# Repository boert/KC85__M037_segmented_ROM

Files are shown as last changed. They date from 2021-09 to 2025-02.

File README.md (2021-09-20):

# KC85__M037_segmented_ROM
Modul für den KC85/3/4/5: Segmentierter ROM in den Größen 32/64/128 kByte

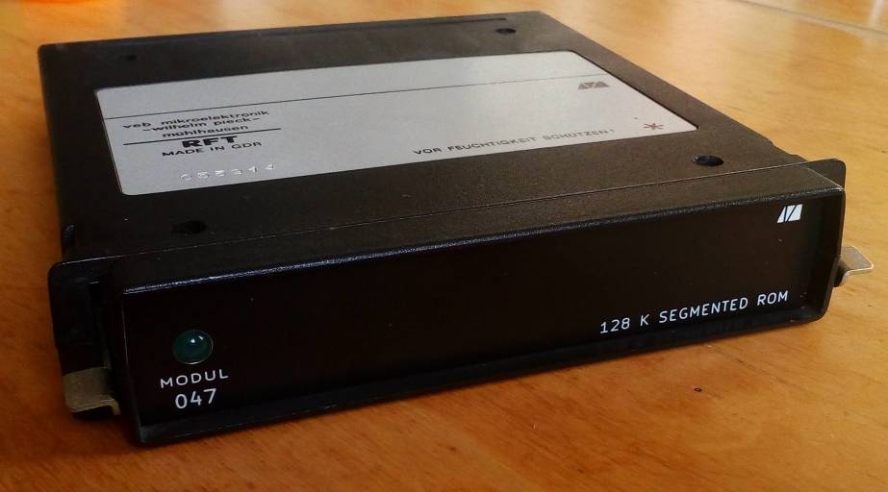
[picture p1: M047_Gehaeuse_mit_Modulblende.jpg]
Modul


optionale Bedienoberfläche

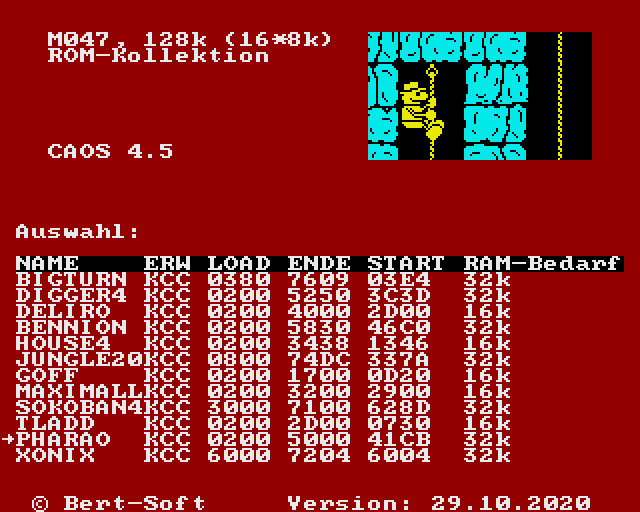
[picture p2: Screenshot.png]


## Verzeichnisübersicht

Verzeichnis             | Inhalt
-----------             | ------
Platine                 | Schaltplan, Layout und Stückliste/BOM
EPROM-Images            | vorgefertigt, für Emulator und EPROM-Brenner
Generator-Software      | um eigene EPROM-Images zu erstellen (C++, Qt5)
ROMSTART                | Menüsoftware, die auf dem Modul läuft (Z80-Assembler)

## Credits

Dieses Projekt nutzt u.a. folgende Software:
- KiCad, https://www.kicad.org/
- pasmo, https://pasmo.speccy.org/
- Python, https://www.python.org/
- Qt, https://www.qt.io/
- ZX7, https://spectrumcomputing.co.uk/entry/27996/ZX-Spectrum/ZX7

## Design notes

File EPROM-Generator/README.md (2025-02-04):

Die Software dient zum Erzeugen von EPROM-Inhalten für KC85-Module vom
Typ M045/M046/M047. Die EPROM-Software ist auf den Modellen KC85/3 und KC85/4 aus Mühlhausener Produktion, sowie den Umbauten zum KC85/5 lauffähig.

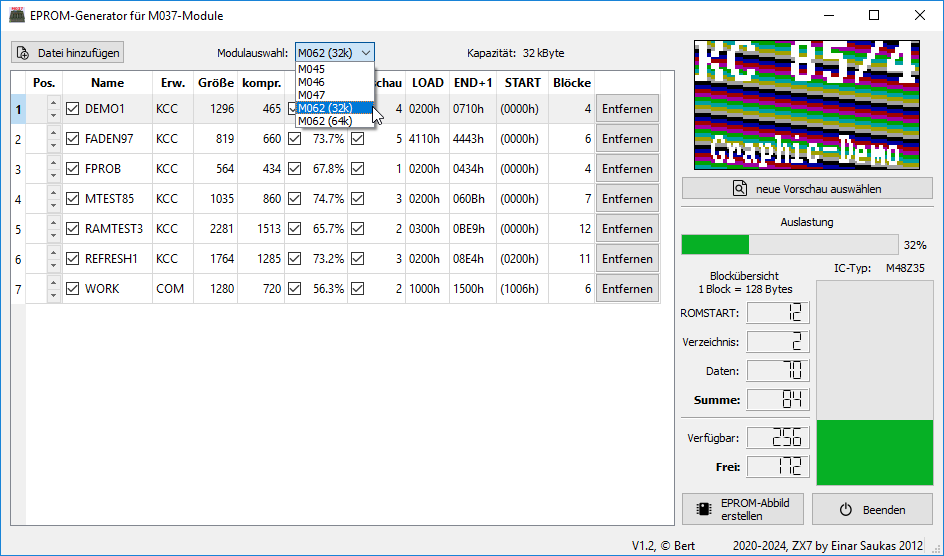
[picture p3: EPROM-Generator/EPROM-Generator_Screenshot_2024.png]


# Bedienung

Im Wesentlich besteht der Programmablauf aus vier Schritten:
1. Auswahl des Modultyps
2. Hinzufügen von KCC-Dateien
3. (optional) Auswahl der Vorschaubilder
4. Erzeugen des EPROM-Abbildes

## Start der Software

Beim Start von der Kommandozeile, können optional eine oder mehrere KCC-Dateien als Parameter mitgegeben werden.
Anschließend öffnet sich das zweigeteilte Hauptfenster. Im linken Teil befindet sich eine Liste der KC-Programme, die zum EPROM hinzugefügt werden sollen. Im rechten Teil befinden sich ein Vorschaubild, Statusinformationen und die Schaltflächen um den EPROM-Inhalt zu generieren bzw. das Programm zu beenden.
Links oben befindet sich die Schaltfläche zum Hinzufügen von Dateien, sowie die Möglichkeit den Modultyp zu ändern.

## Modultyp

Die Wahl des Modultypes wirkt sich auf den verfügbaren Speicherplatz aus.
Der ausgewählte Modultyp muß zu den verwendeten EPROMs und den Jumpereinstellungen auf der Platine passen. Die ROMSTART-Software, welche im KC ausgeführt wird, ist auf den jeweiligen Modultyp zugeschnitten.

## Programme

Momentan werden nur KCC-Dateien unterstützt. KCC-Dateien bestehen aus Blöcken zu je 128 Byte. Im ersten Block, dem Vorblock, sind Zusatzinformationen, wie der Name und die verwendeten Adressen hinterlegt (siehe auch [1]).
Diese Informationen werden in der Tabelle auf der linken Seite dargestellt, können dort aber nicht geändert werden.
Die Programmgröße wird in Bytes angegeben. Da in ROMSTART der Entpacker DZX7 [2] integriert ist, werden die Programme, bei denen es sich lohnt komprimiert im EPROM abgelegt.
Die komprimierte Größe und das Kompressionsverhältnis werden ebenfalls in der Tablle dargestellt. Die Spalte "Blöcke" enthält die Zahl der tatsächlich im EPROM benötigten 128 Byte-Blöcke.

Folgende Einstellungen können in der Tabelle vorgenommen werden:
- Ändern der Reihenfolge (dazu die Pfeile in Spalte "Pos." verwenden)
- Auswahl ob das Programm mit in den EPROM übernommen wird (Häckchen in Spalte "Name")
- Auswahl ob das Programm komprimiert wird (Häckchen in Spalte "Ratio")
- Auswahl eine Vorschau mit übernommen wird (Häckchen in Spalte "Vorschau")
- Dauerhaftes Entfernen eines Listeneintrags (letzte Spalte)

## Vorschau

Zu jedem Programmeintrag kann eine Vorschau ausgewählt bzw. angezeigt werden.
Um eine neue Vorschau zu erzeugen, wird die entsprechende Schaltfläche ausgewählt.
Es öffnet sich ein Dialog in dem ggf. die bisherige Vorschau dargestellt wird.
Im Dialog bestehen folgende Möglichkeiten:
- Öffnen einer PNG bzw. JPEG-Datei
- Öffnen einer PIC-Datei (Bildschirmauszug vom KC85/3)
- Öffnen einer PIP/PIF-Datei (Bildschirmauszug vom KC85/4)

Anschließend wird in der linken oberen Ecke ein Auswahlrechteck dargestellt, welches mit der Maus verschoben werden kann. Wenn der richtige Ausschnitt gefunden wurde, kann die Auswahl mit "Speichern" als ICN-Datei (Icon) gesichert werden.

Eine gute Möglichkeit um an passende Vorschaubilder zu erzeugen, bietet der Emulator JKCEMU [3].
Der Emulator läßt sich pausieren (Alt-P) und man kann den Bildschriminhalt als Datei sichern (Datei -> Bildschirmausgabe -> als Bilddatei speichern).
Eine nähere Erklärung für PIC/PIP/PIF-Dateien findet sich unter [4]. Im Wesentlichen sind es Bildschirmabzüge der jeweiligen KC-Systeme.
Auf dem System selbst können die Hilfsprogramme PICGEN.KCC oder PICGEN.COM verwendet werden.
Anmerkung: Um PIC/PIP/PIF-Dateien als Vorschau verwenden zu können, müssen diese unkomprimiert vorliegen.

## Statusanzeige

Unterhalb der Vorschau befindet sich eine Statusanzeige.
Dort kann man sehen, wieviel vom Gesamtspeicher schon verwendet wird (waagerechter Balken).
Die vier senkrechten Balken stehen für die einzelnen EPROM-Schaltkreise.
Falls mehr Programme ausgewählt sind, als Platz vorhanden ist, wird der Balken rot eingefärbt.
Es ist dann nicht möglich ein EPROM-Auszug zu erstellen.

Der Speicher im EPROM besteht aus drei Teilen:
1. der Verwaltungs- und Startprogramm (ROMSTART)
2. den Verzeichniseinträgen (28 Byte/Eintrag)
3. den Programmdaten
Der benötigte Platz für alle drei Teile wird unter "Summe" angezeigt.
Darunter ist die Zahl der verfügbaren Blöcke zu sehen (Modulabhängig).
Und anschließen ist unter "Frei" die Zahl der freien Blöcke abgebildet.

## Abbild erstellen

Wenn alle benötigten Programme hinzugefügt und die gewünschten Vorschaubilder erstellt sind, wird mit der Schaltfläche "EPROM-Abbild erstellen" die Datei "EPROM_M04?.bin" erstellt. Diese Datei kann sofort im Emulator getestet werden.
Zusätzlich werden die Dateien "EPROM_M04?.bin_ROM?" erstellt. Diese sind für den EPROM-Brenner gedacht.

# Quellenverweise

[1] KC85/5 System-Handbuch CAOS 4.6 bis 4.8, 3.8.2 Dateiaufbau

[2] ZX7, Einar Saukas, https://worldofspectrum.org/infoseekid.cgi?id=0027996

[3] JKCEMU, Jens Müller, http://www.jens-mueller.org/jkcemu/

[4] KC-Bildformate intern, Ralf Kästner, KC-News 2/95, http://kc85.info/index.php/kc-news/265-kc-news-2-1995.html?start=13

# Nachtrag 02/2020

Bei der Nutzung mit einem Modul M052 (USB) kommt es zu Problemen wenn am M052 die Tastatur genutzt werden soll und das ROM-Modul im Schacht 08 steckt.
In diesem Fall verdeckt ein aktiviertes ROM-Modul die Interruptroutinen im ROM des M052.
Workaround: Das ROM-Modul muß auf einem höheren Steckplatz als das M052 Modul betrieben werden. Um dennoch in den Genuß von Autostart zu kommen, läßt sich auf dem verwendeten USB-Stick eine Datei INITIAL.UUU anlegen, welche z.B. folgende Kommandos enthält:
SWITCH C C1
ROMSTART

# Nachtrag 02/2025

Falls es zu Artefakten bei der Erstellung von Vorschaubildern kommen sollte, gibt es hier weitere Hinweise.

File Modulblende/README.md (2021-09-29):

# KiCad-Projekt für die Modulblende

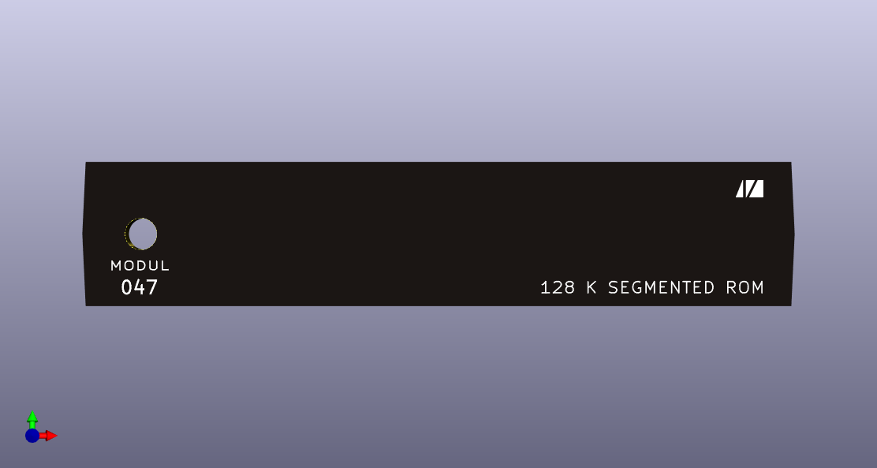
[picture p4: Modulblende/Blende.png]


Vielen Dank an Mirco (ch1frd)!

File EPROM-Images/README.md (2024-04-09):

# EPROM-Inhalte

## M033__TYPESTAR

* Typestar 90 und RAMDOS V2.0

Hier gibt es weitere Informationen zu Typestar: http://www.mpm-kc85.de/html/m033_typestar.htm

## M047__12_Spiele_KC855

diese Spiele laufen alle auf dem KC85/4 mit CAOS 4.2 bis CAOS 4.8

ROMSTART vom 5.12.2020

* Bennion.kcc
* Bigturn
* DELIRO
* DIGGER4
* ENTERPRISE
* GOFF
* HOUSE4
* JUNGLE21
* KCLADDER
* MAXIMALL
* SOKOBAN4
* XONIX

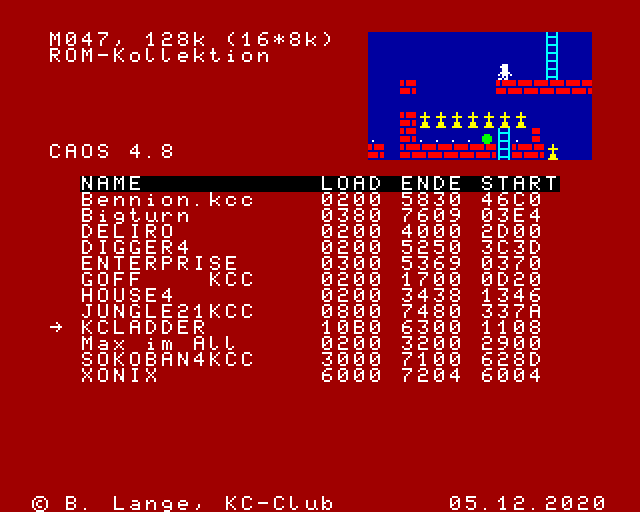
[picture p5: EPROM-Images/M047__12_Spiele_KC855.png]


## M047__14_Spiele_KC853

diese Spiele sind für den KC85/3 gedacht

ROMSTART vom 5.12.2020

* Bennion.kcc
* Bigturn
* BOULDERDASH
* Breakin
* DELIRO
* DIGGER3
* GOFF2
* GOLDRUSH
* HELI
* KEX3
* PHARAO+
* PURSUIT3
* PYRAMIDE
* XONIX

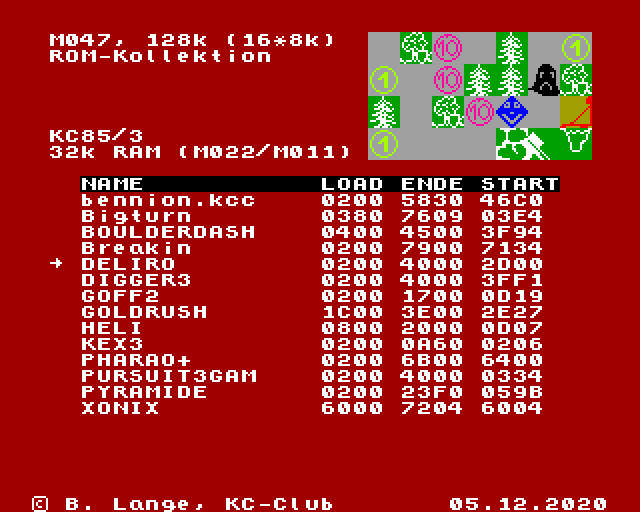
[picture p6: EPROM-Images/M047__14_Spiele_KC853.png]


## M062__7_Tools_KC854

Ein paar kleine Demos und Tools für den KC85/4 bzw. /5

ROMSTART vom 9.4.2024

* DEMO
* FADEN97
* FPROB (Farben probieren)
* MTEST85 (Speichertest)
* RAMTEST3 (Speichertest)
* REFRESH1 (Refreshtest für M036)
* WORK (Hex-Editor)

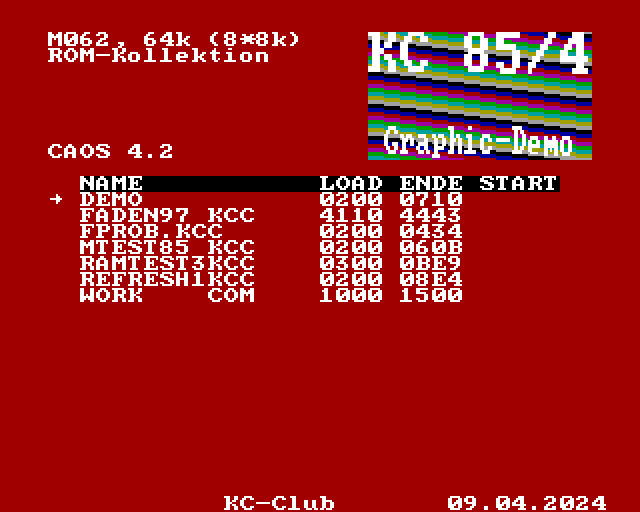
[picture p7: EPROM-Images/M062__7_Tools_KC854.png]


## Copyright

Das Copyright der Software liegt beim jeweiligen Autor!

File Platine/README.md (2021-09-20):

# Unterlagen zur Leiterplatte

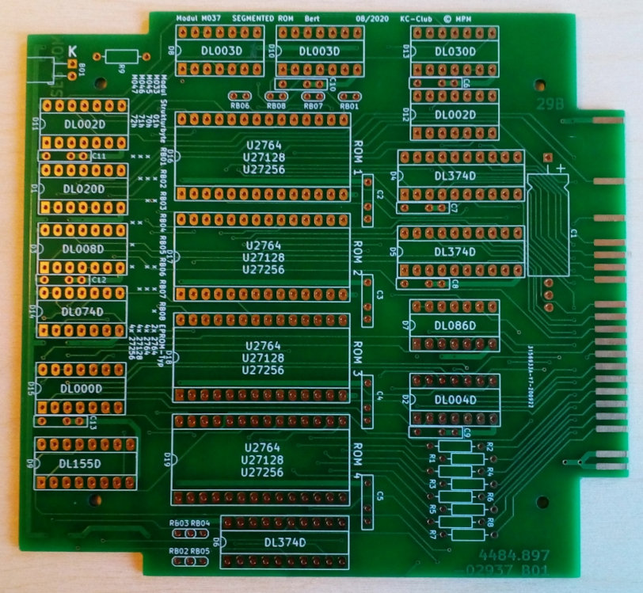
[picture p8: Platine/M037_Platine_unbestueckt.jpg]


Dokument            | Verweis
--------            | -------
Schaltplan          | [M037_Schaltplan.pdf](https://raw.githubusercontent.com/boert/KC85__M037_segmented_ROM/main/Platine/M037_Schaltplan.pdf)
Layout              | [M037_Platine.pdf](https://raw.githubusercontent.com/boert/KC85__M037_segmented_ROM/main/Platine/M037_Platine.pdf)
Stückliste/BOM      | [M037_Stueckliste.xls](https://raw.githubusercontent.com/boert/KC85__M037_segmented_ROM/main/Platine/M037_Stueckliste.xls)
Bestückungshilfe    | [M037_Bestueckhilfe.html](https://raw.githubusercontent.com/boert/KC85__M037_segmented_ROM/main/Platine/M037_Bestueckhilfe.html)

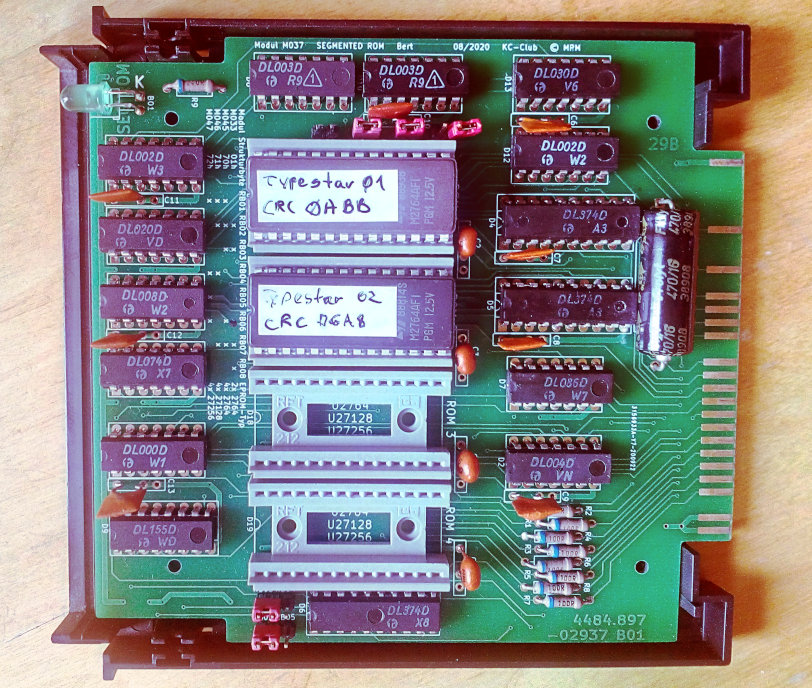
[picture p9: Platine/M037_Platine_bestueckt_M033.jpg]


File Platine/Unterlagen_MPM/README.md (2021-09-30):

# Unterlagen vom VEB Mikroelektronik „Wilhelm Pieck“ Mühlhausen

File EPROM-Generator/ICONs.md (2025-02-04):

# Probleme beim Erstellen von Vorschaubildern (Icons)

Es gibt Fälle, bei denen die EPROM-Generator-Software beim Erzeugen der Vorschaubilder unerwünschte Artefakte erzeugt:
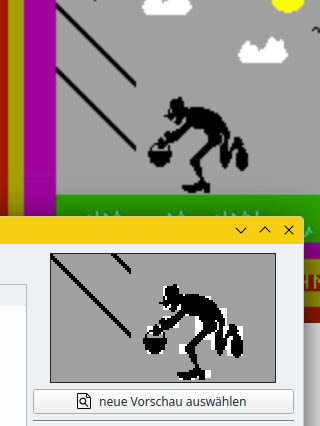
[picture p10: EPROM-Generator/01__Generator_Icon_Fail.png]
fehlerhaftes Icon


Dies tritt bei der Verwendung von Screenshots im PNG-Format auf.
Dort muß die Funktion pixmap_to_bws [1] für  jeweils acht nebeneinanderliegende RGB24-Bildpunkte das passende KC85-Farbbyte finden.
Das klappt offensichtlich nicht immer.

Um trotzdem zu schönen Vorschaubilder zu kommen, gibt es einige Workarounds:

## PICGEN.COM

Damit kann der Inhalt des jeweils nicht angezeigten Bildes als PIP-/PIF-Datei abspeichern werden. Das Programm [2] läuft unter MicroDOS bzw. CP/M und benötigt ein D004 bzw. D008.

## PICGEN.KCC

Das Tool gibt es auch in einer Variante [3] die direkt auf dem Grundgerät D001 läuft.

## JKCEMU
Im JKCEMU [4], dem umfrangreichsten KC-Emulator läst sich die Speicherfunktion nutzen, um PIP- bzw. PIF-Dateien zu erstellen.

Als Dateiformat wird KCC gewählt, der Speicherbereich geht von 7FFFh bis A7FFh und als Dateiendung wählt man PIP.
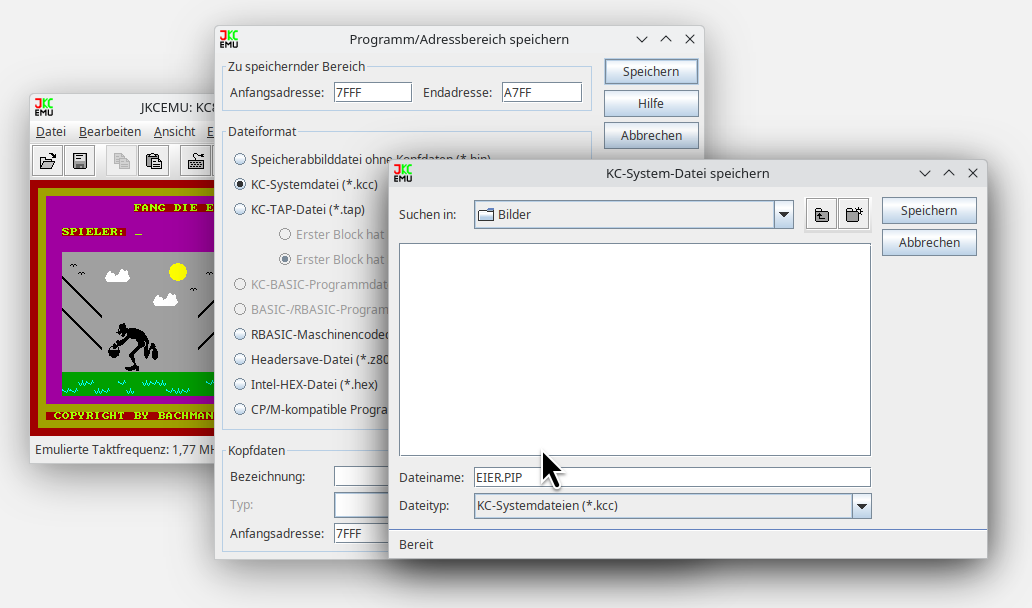
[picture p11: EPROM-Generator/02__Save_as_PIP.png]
Speichern als PIP

Der Bildspeicher startet zwar bei 8000h, aber das PIP-Format hat noch ein Kennbyte, welches direkt vor den Daten kommt. Richtigerweise müßte man das für eine unkomprimierte PIP-Datei auf 5 setzen.

Dann schaltet man mit ESC-9 auf die Farbebene um. Anschließend wird wieder gespeichert:
Das Dateiformat ist wieder KCC, der Speicherbereich geht wieder von 7FFFh bis A7FFh und als Dateiendung wählt man nun PIF.
Die Umschaltung auf die Farbebene klappt aber nur, wenn gerade ein Eingabefeld aktiv ist (CAOS-UP KBD oder KBDS).
Für unkomprimierte PIF-Dateien wäre das richtige Kennbyte die 4.

Anschließend lassen sich die PIP- und die PIF-Datei in der EPROM-Generator-Software auswählen:
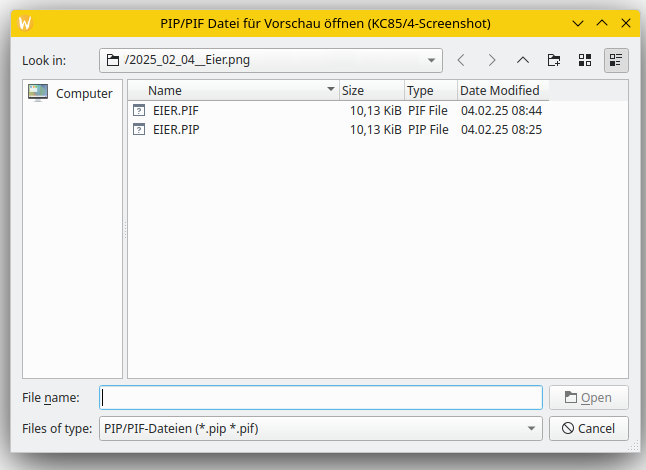
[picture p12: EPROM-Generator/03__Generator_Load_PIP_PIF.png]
Load PIP and PIF

Ggf. falsche Kennbytes werden ignoriert, aber die PIP- bzw. PIF-Dateien müssen unkomprimiert vorliegen.

# Links

[1] https://github.com/boert/KC85__M037_segmented_ROM/blob/main/EPROM-Generator/kc85color.cpp#L72

[2] http://www.kc85.info/index.php/download.html?view=download&id=192:picgen20&catid=6

[3] http://www.kc85.info/index.php/download.html?view=download&id=262:picgen&catid=27

[4] JKCEMU, Jens Müller, http://www.jens-mueller.org/jkcemu/

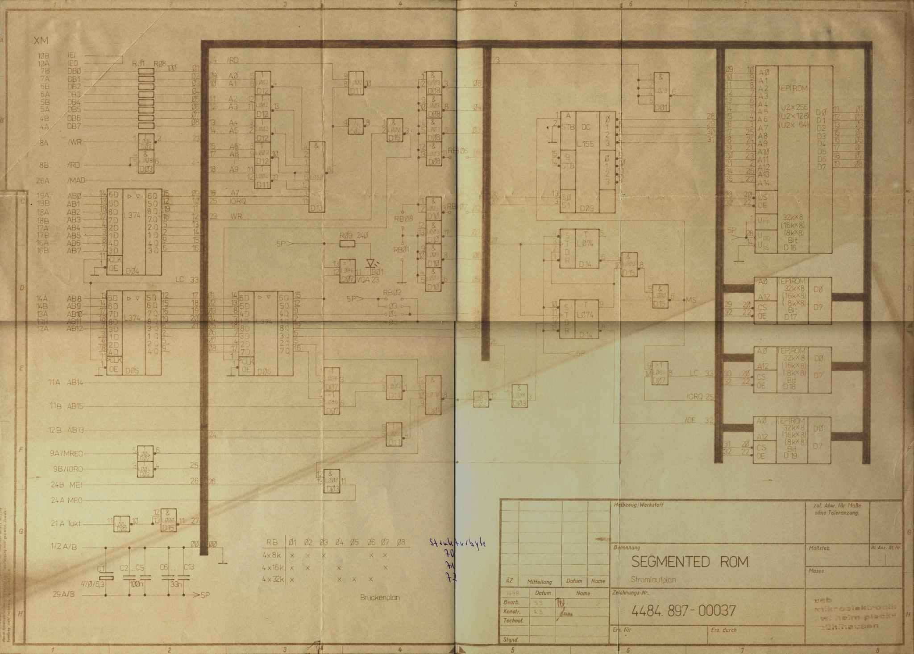
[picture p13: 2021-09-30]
Platine/Unterlagen_MPM/M037_Schaltplan.jpg

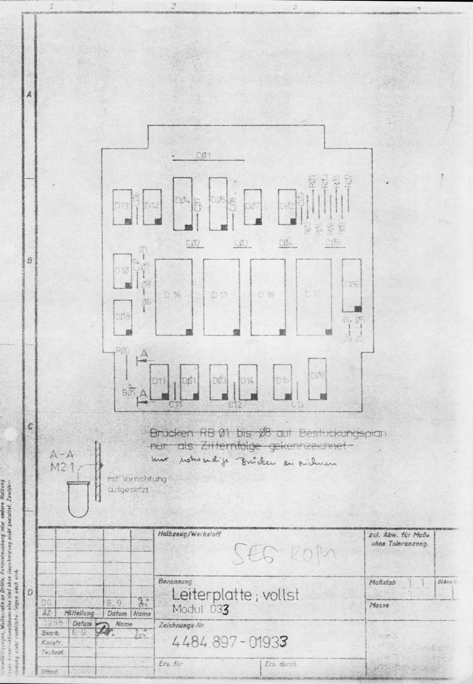
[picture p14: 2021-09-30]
Platine/Unterlagen_MPM/M037_Leiterplatte.jpg

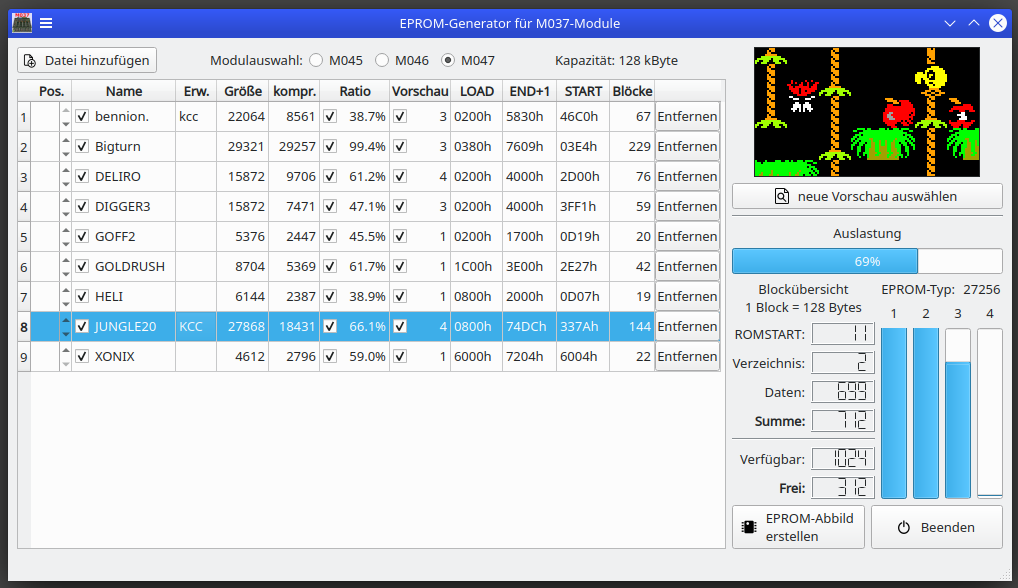
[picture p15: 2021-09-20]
EPROM-Generator/EPROM-Generator_Screenshot.png

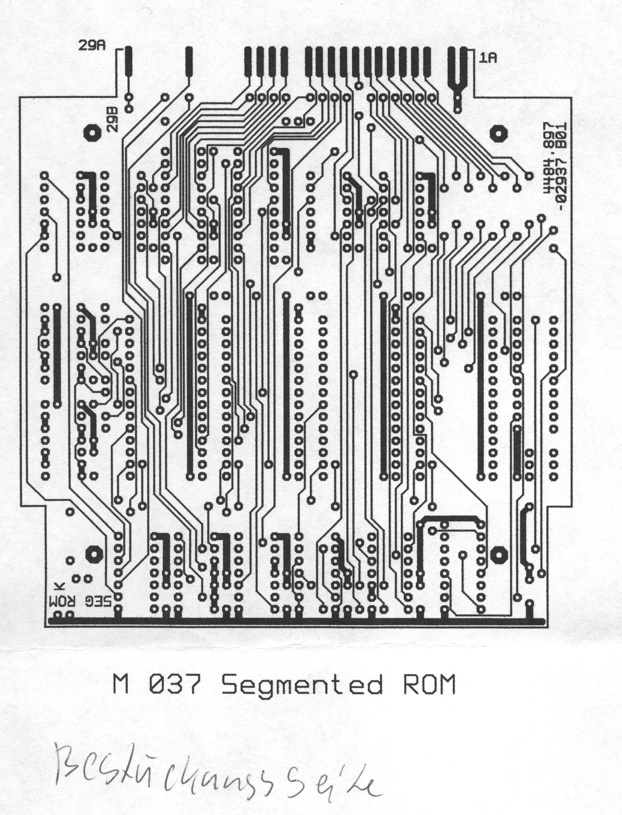
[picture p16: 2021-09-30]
Platine/Unterlagen_MPM/M037_Bestueckungsseite.jpg

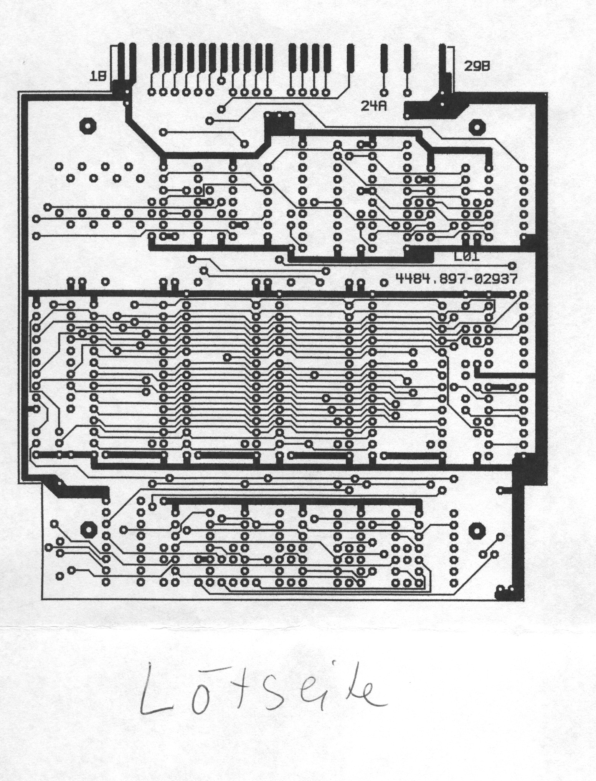
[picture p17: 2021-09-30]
Platine/Unterlagen_MPM/M037_Loetseite.jpg

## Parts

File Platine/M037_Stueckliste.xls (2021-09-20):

Position | Variante | Bauteil | Anzahl | Wert | Größe/Raster | Reichelt | Preis | Segor | Preis
 | Kondensatoren
1 | alle | C1 | 1 | 470µ/6,3V | 21 x 8 (D) mm | AX 105 470/10 | 0.36 € | ELAX 470u- 10 | 1.90 €
2 | alle | C6, C7, C8, C9, C10, C11, C12, C13 | 8 | 33n | 5 (7,5) mm | Z5U-5 33N | 0.03 € | 33n-R5.0-X7R | 0.18 €
3 | alle | C2, C3, C4, C5 | 4 | 100n | 5 (7,5) mm | X7R-5 100N | 0.07 € | u10-R5.0-Z5U | 0.09 €
 | Widerstände
4 | alle | R9 | 1 | 240 Ohm | 10 mm | VI MBB02070C2400 | 0.04 € | MF 240R-1% | 0.05 €
5 | alle | R1, R2, R3, R4, R5, R6, R7, R8 | 8 | 100 Ohm | 10 mm | VI MBB02070C1000 | 0.04 € | MF 100R-1% | 0.05 €
 | LED
6 | alle | B01 | 1 | VQA23 | 5 mm, LED | LED 5MM GN | 0.07 € | LED 5 gn-dif | 0.10 €
 | Stiftleisten/Steckbrücken
7 | alle | RB01, RB06, RB07, RB08 | 4 | 2polig | 2,54 mm | RND 205-00632 | 0.04 € | SL1x 2-180G | 0.07 €
8 | alle | RB02, RB03, RB04, RB05 | 2 | 3polig | 2,54 mm | RND 205-00624 | 0.03 € | SL1x 3-180G | 0.10 €
9 | alle | Jumper | 5 |  | 2,54 mm | JUMPER 2,54 SW | 0.02 € | Jumper | 0.08 €
 | Schaltkreise/IC
10 | alle | D8, D10 | 2 | DL003 | DIP14 | LS 03 | 0.22 € | 74LS 03N | 0.70 €
11 | alle | D11, D12 | 2 | DL002 | DIP14 | LS 02 | 0.59 € | 74LS 02N | 0.80 €
12 | alle | D1 | 1 | DL020 | DIP14 | LS 20 | 0.97 € | 74LS 20N | 0.80 €
13 | alle | D2 | 1 | DL004 | DIP14 | LS 04 | 0.65 € | 74LS 04N | 0.80 €
14 | alle | D3 | 1 | DL008 | DIP14 | LS 08 | 0.67 € | 74LS 06N | 1.00 €
15 | alle | D7 | 1 | DL086 | DIP14 | LS 86 | 0.67 € | %
16 | alle | D13 | 1 | DL030 | DIP14 | LS 30 | 0.78 € | 74LS 30N | %
17 | alle | D14 | 1 | DL074 | DIP14 | LS 74 | 0.56 € | 74LS 74AN | 0.60 €
18 | alle | D15 | 1 | DL000 | DIP14 | LS 00 | 0.97 € | 74LS 00N | 1.10 €
19 | alle | D9 | 1 | DL155 | DIP16 | % |  | 74LS 155N | 1.70 €
20 | alle | D4, D5, D6 | 3 | DL374 | DIP20 | LS 374 | 0.74 € | 74LS 374N | 1.00 €
 | Speicherschaltkreise/EPROM
21 | M047 | D16, D17, D18, D19 | 4 | U27256 | DIP28 | 27C256-100 | 3.02 € | 27C256-120 | 7.50 €
22 | M046 | D16, D17, D18, D19 | 4 | U27128 | DIP28 | % | 0.00 € | 27C128-200 | 9.20 €
23 | M045 | D16, D17, D18, D19 | 4 | U2764 | DIP28 | % | 0.00 € | % | 0.00 €
24 | M033 | D16, D17 | 2 | U2764 | DIP28 | % | 0.00 € | % | 0.00 €
 | Schaltkreisfassungen
25 | nach Befarf | IC-Fassung für D1, D2, D3, D7, D8, D10, D11, D12, D13, D14, D15 | 11 |  | DIP14 | GS 14 | 0.05 € | DILLC14-U | 0.14 €
26 | nach Befarf | IC-Fassung für D9 | 1 |  | DIP16 | GS 16 | 0.06 € | DILLC16-U | 0.16 €
27 | nach Befarf | IC-Fassung für D4, D5, D6 | 3 |  | DIP20 | GS 20 | 0.07 € | DILLC20-U | 0.20 €
28 | alle | IC-Fassung für D16, D17, D18, D19 | 4 |  | DIP28W | GS 28 | 0.10 € | DILLC28-U | 0.30 €

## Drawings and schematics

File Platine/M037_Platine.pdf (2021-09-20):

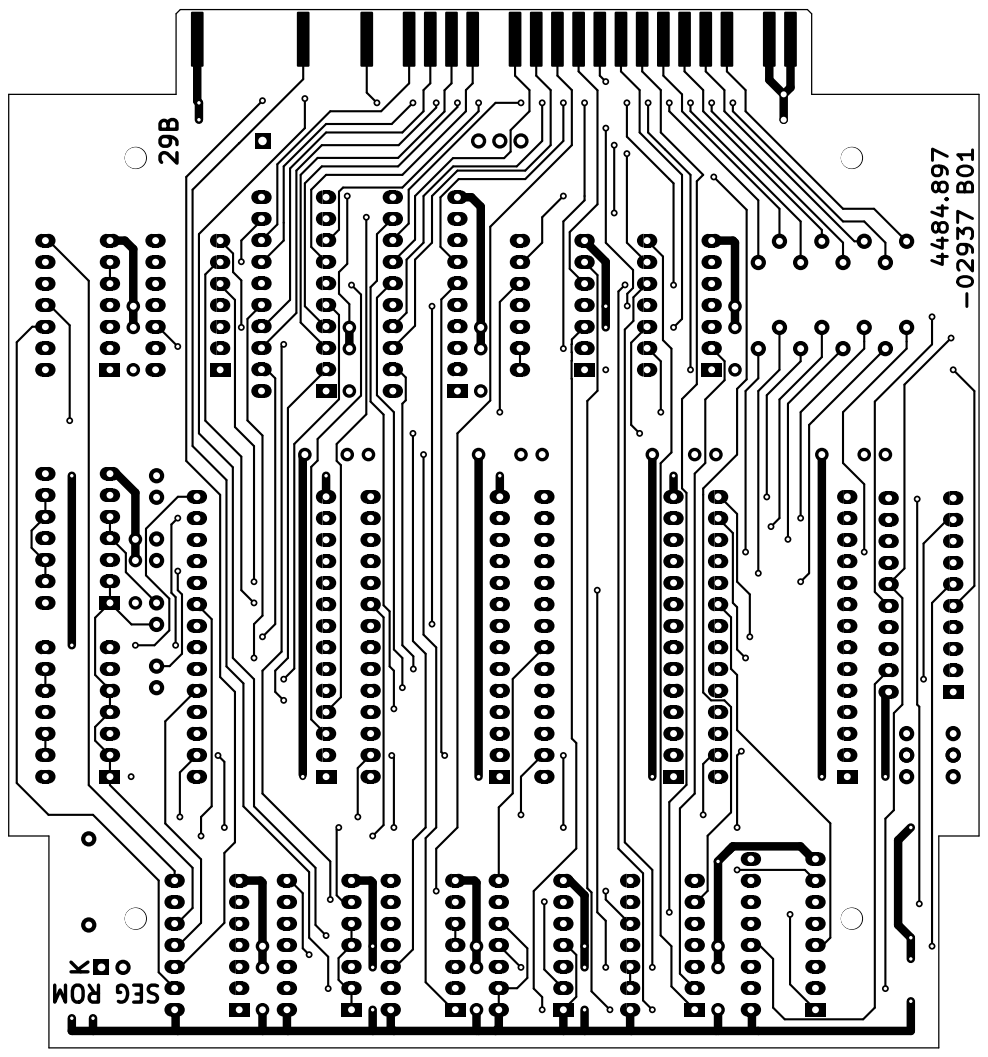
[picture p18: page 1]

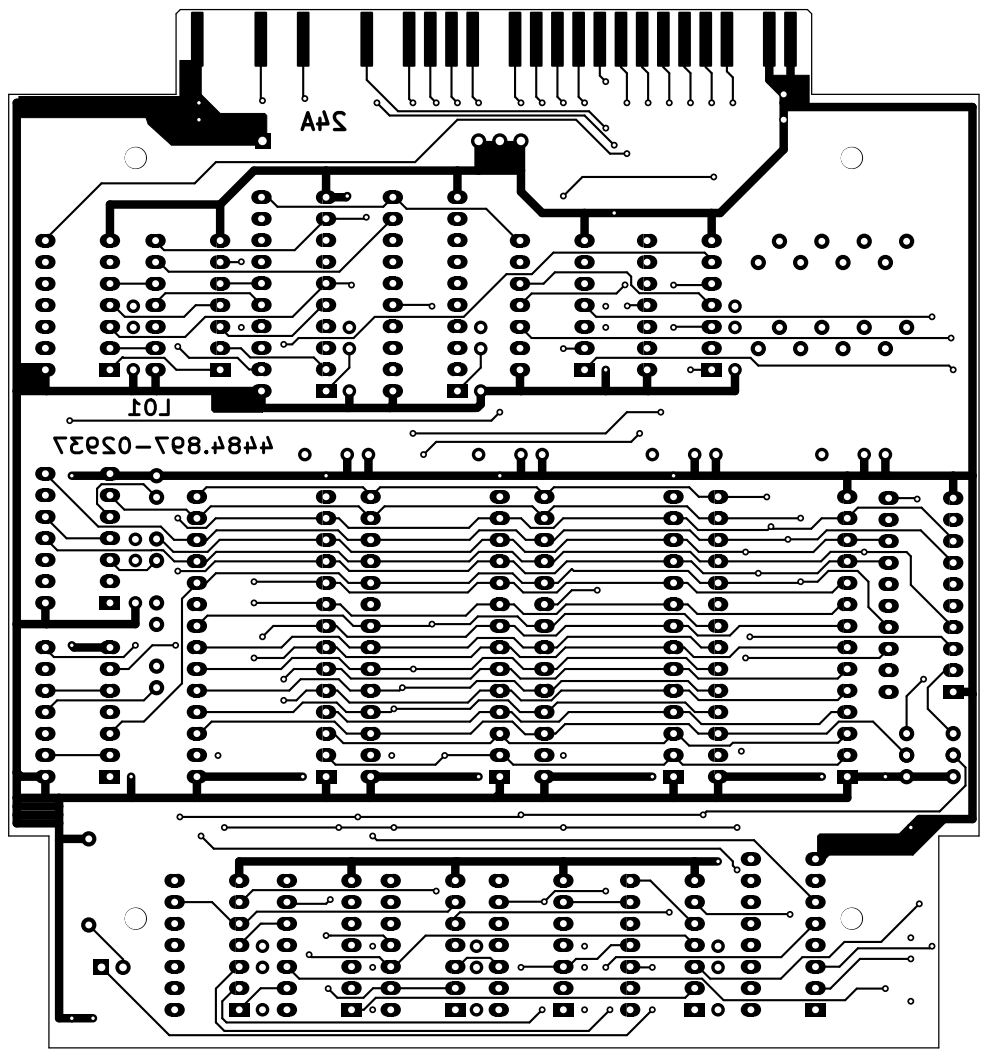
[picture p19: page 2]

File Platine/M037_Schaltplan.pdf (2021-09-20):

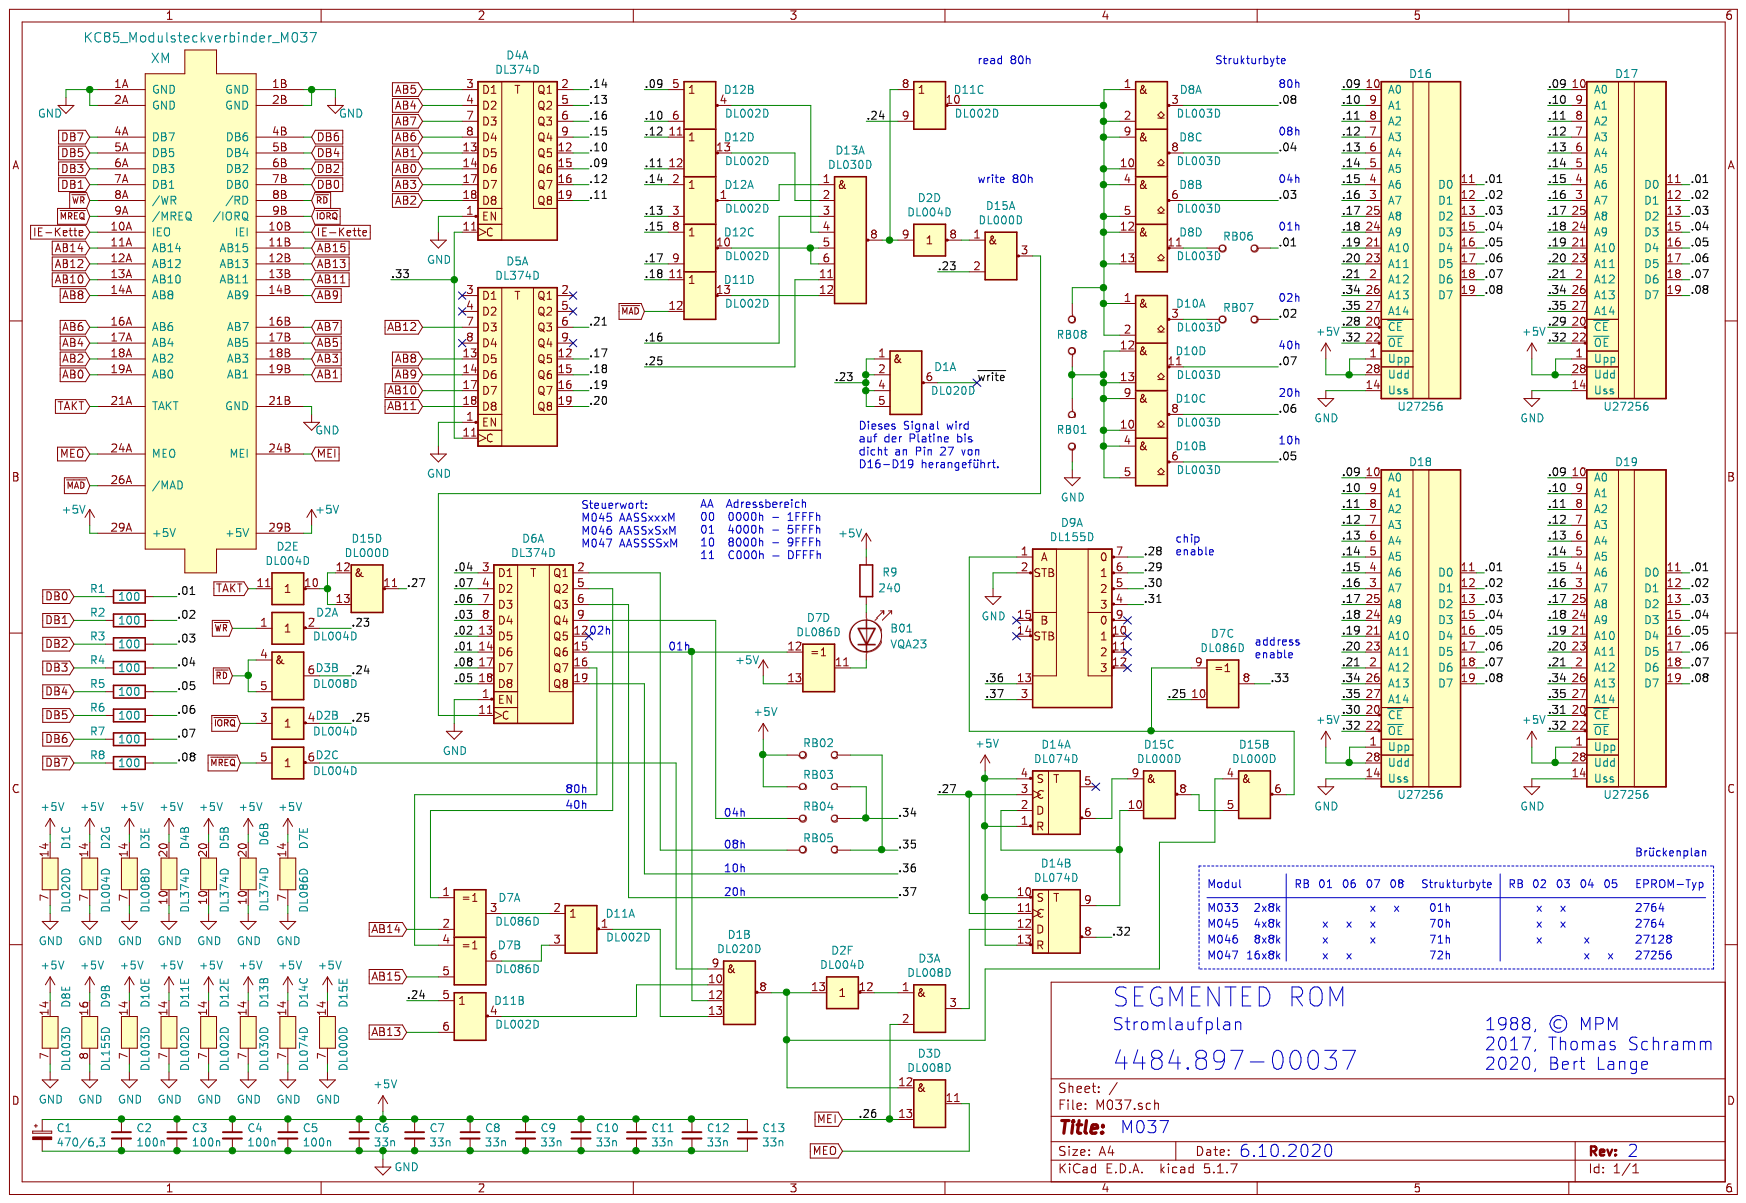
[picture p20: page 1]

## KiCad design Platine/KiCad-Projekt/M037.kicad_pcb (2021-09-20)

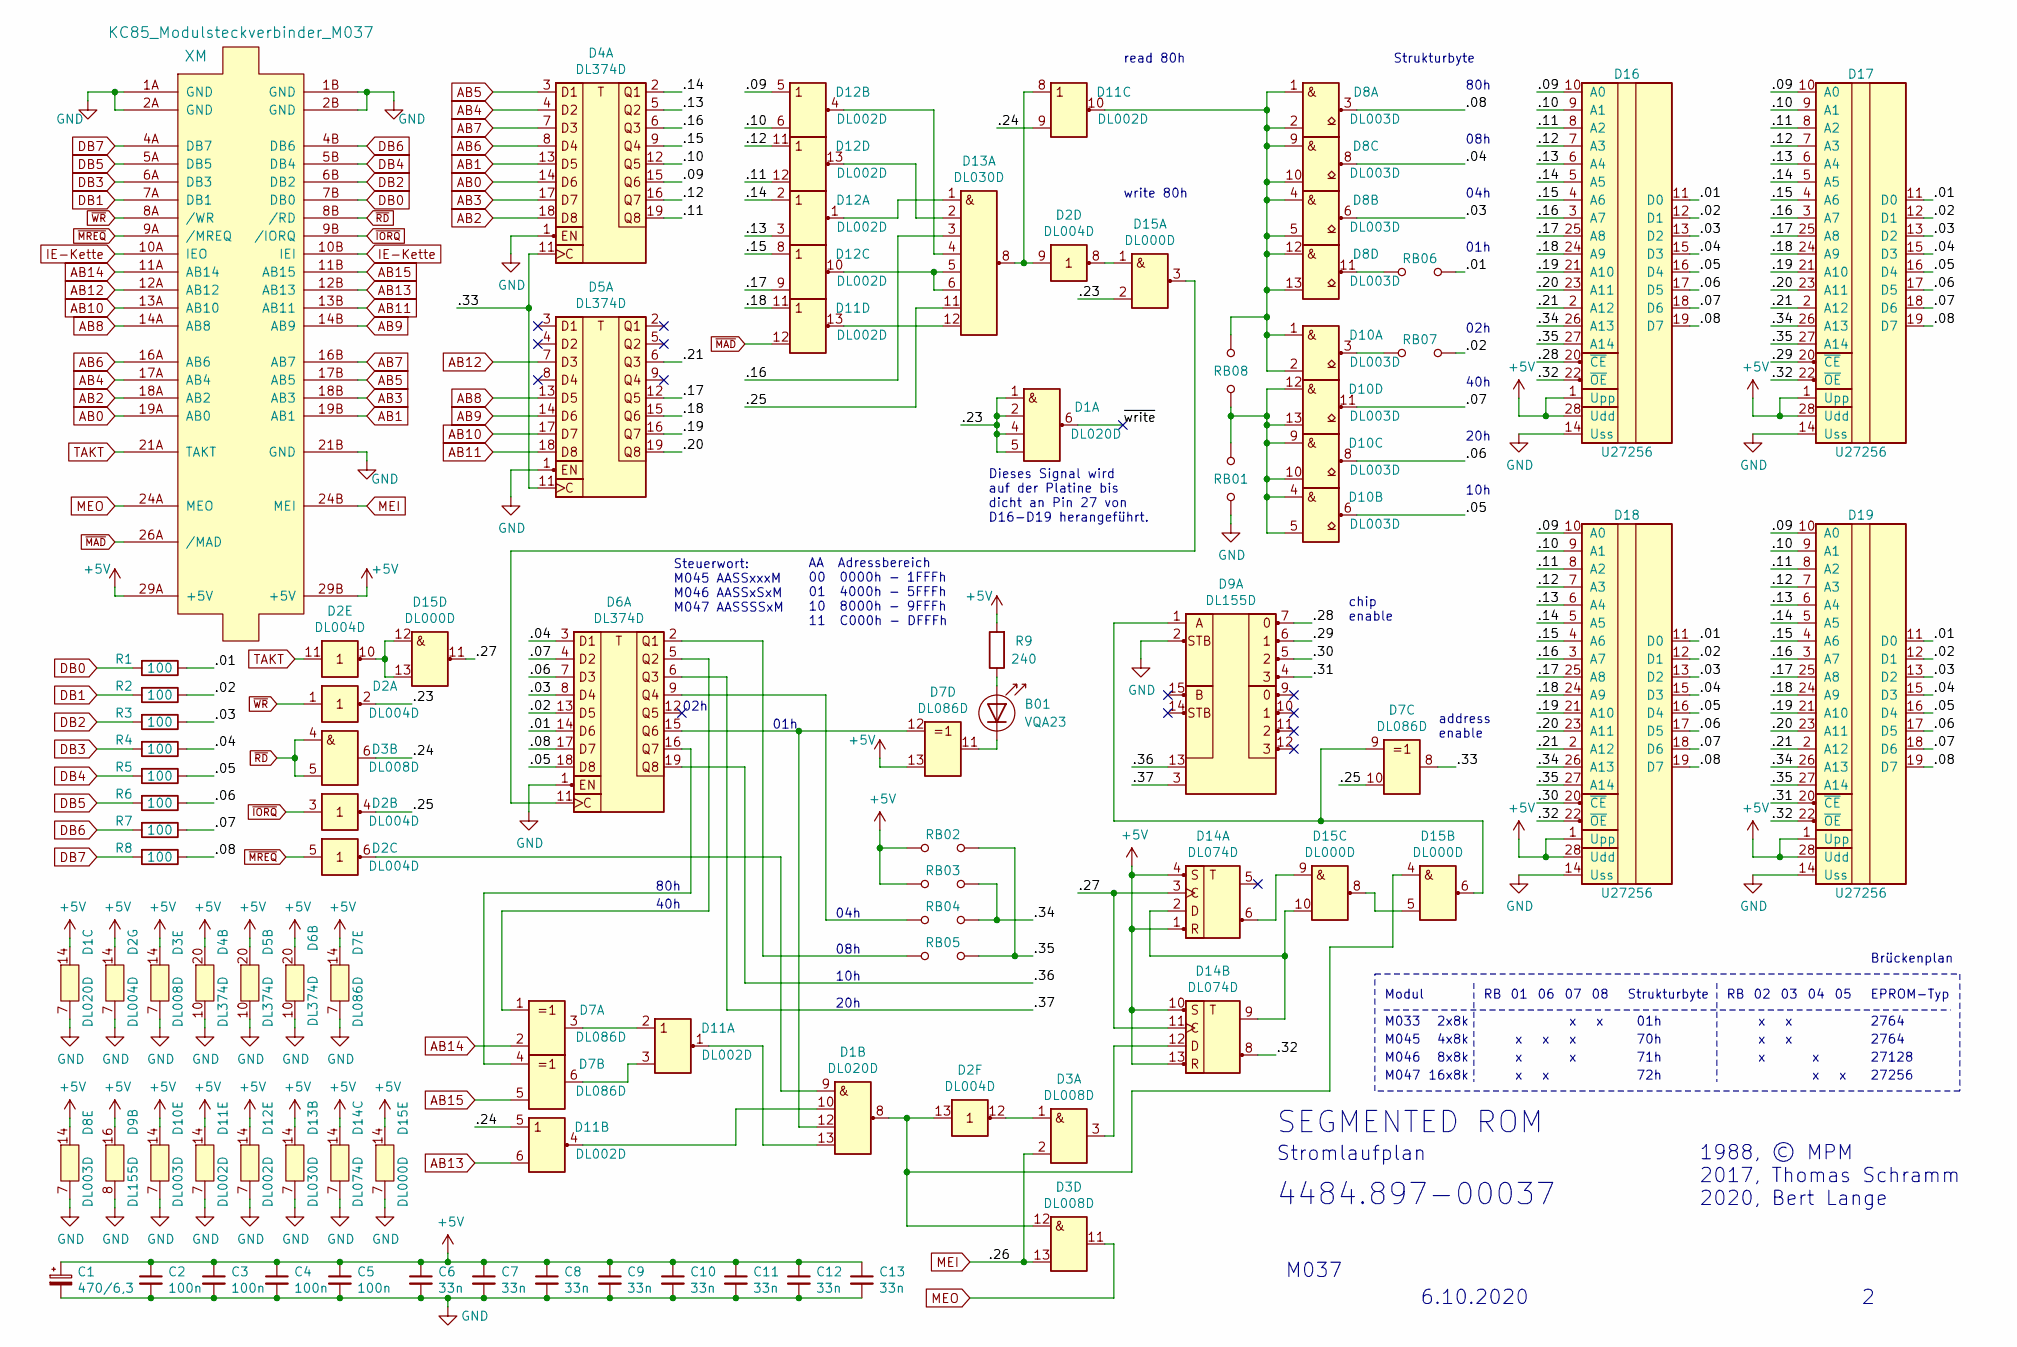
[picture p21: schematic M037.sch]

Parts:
B01: VQA23; LED_D5.0mm_Horizontal_O3.81mm_Z3.0mm
C1: 470/6,3; CP_Axial_L21.0mm_D10.0mm_P25.0mm...35.0mm_Horizontal
C2, C3, C4, C5: 100n; C_Disc_D8.0mm_W2.0mm_P5.00mm_P7.50mm
C6, C7, C8, C9, C10, C11, C12, C13: 33n; C_Disc_D8.0mm_W2.0mm_P5.00mm_P7.50mm
D1: DL020D; DIP-14_W7.62mm_Socket_LongPads
D2: DL004D; DIP-14_W7.62mm_Socket_LongPads
D3: DL008D; DIP-14_W7.62mm_Socket_LongPads
D4, D5, D6: DL374D; DIP-20_W7.62mm_Socket_LongPads
D7: DL086D; DIP-14_W7.62mm_Socket_LongPads
D8, D10: DL003D; DIP-14_W7.62mm_Socket_LongPads
D9: DL155D; DIP-16_W7.62mm_Socket_LongPads
D11, D12: DL002D; DIP-14_W7.62mm_Socket_LongPads
D13: DL030D; DIP-14_W7.62mm_Socket_LongPads
D14: DL074D; DIP-14_W7.62mm_Socket_LongPads
D15: DL000D; DIP-14_W7.62mm_Socket_LongPads
D16, D17, D18, D19: U27256; DIP-28_W15.24mm_Socket_LongPads
R1, R2, R3, R4, R5, R6, R7, R8: 100; R_Axial_L6.3mm_D2.0mm_P10.16mm_Horizontal
R9: 240; R_Axial_DIN0207_L6.3mm_D2.5mm_P10.16mm_Horizontal
RB01, RB02, RB03, RB04, RB05, RB06, RB07, RB08: Brücke; TestPoint_2Pads_Pitch2.54mm_Drill0.8mm
XM: KC85_Modulsteckverbinder_M037

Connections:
+5V: C1.1, C2.1, C3.1, C4.1, C5.1, C6.1, C7.1, C8.1, C9.1, C10.1, C11.1, C12.1, C13.1, D1.14 (Vcc), D2.14 (Vcc), D3.14 (Vcc), D4.20 (Vcc), D5.20 (Vcc), D6.20 (Vcc), D7.13 (B4), D7.14 (Vcc), D8.14 (Vcc), D9.16 (Vcc), D10.14 (Vcc), D11.14 (Vcc), D12.14 (Vcc), D13.14 (Vcc), D14.1 (R1), D14.4 (S1), D14.10 (S2), D14.13 (R2), D14.14 (Vcc), D15.14 (Vcc), D16.1 (Upp), D16.28 (Udd), D17.1 (Upp), D17.28 (Udd), D18.1 (Upp), D18.28 (Udd), D19.1 (Upp), D19.28 (Udd), R9.2, RB02.1, RB03.1, XM.29A (+5V), XM.29B (+5V); also elsewhere on the board
/.01: D6.14 (D6), D16.11 (D0), D17.11 (D0), D18.11 (D0), D19.11 (D0), R1.1, RB06.2
/.02: D6.13 (D5), D16.12 (D1), D17.12 (D1), D18.12 (D1), D19.12 (D1), R2.1, RB07.2
/.03: D6.8 (D4), D8.6 (Y2), D16.13 (D2), D17.13 (D2), D18.13 (D2), D19.13 (D2), R3.1
/.04: D6.3 (D1), D8.8 (Y3), D16.15 (D3), D17.15 (D3), D18.15 (D3), D19.15 (D3), R4.1
/.05: D6.18 (D8), D10.6 (Y2), D16.16 (D4), D17.16 (D4), D18.16 (D4), D19.16 (D4), R5.1
/.06: D6.7 (D3), D10.8 (Y3), D16.17 (D5), D17.17 (D5), D18.17 (D5), D19.17 (D5), R6.1
/.07: D6.4 (D2), D10.11 (Y4), D16.18 (D6), D17.18 (D6), D18.18 (D6), D19.18 (D6), R7.1
/.08: D6.17 (D7), D8.3 (Y1), D16.19 (D7), D17.19 (D7), D18.19 (D7), D19.19 (D7), R8.1
/.09: D4.15 (Q6), D12.5 (A2), D16.10 (A0), D17.10 (A0), D18.10 (A0), D19.10 (A0)
/.10: D4.12 (Q5), D12.6 (B2), D16.9 (A1), D17.9 (A1), D18.9 (A1), D19.9 (A1)
/.11: D4.19 (Q8), D12.12 (B4), D16.8 (A2), D17.8 (A2), D18.8 (A2), D19.8 (A2)
/.12: D4.16 (Q7), D12.11 (A4), D16.7 (A3), D17.7 (A3), D18.7 (A3), D19.7 (A3)
/.13: D4.5 (Q2), D12.3 (B1), D16.6 (A4), D17.6 (A4), D18.6 (A4), D19.6 (A4)
/.14: D4.2 (Q1), D12.2 (A1), D16.5 (A5), D17.5 (A5), D18.5 (A5), D19.5 (A5)
/.15: D4.9 (Q4), D12.8 (A3), D16.4 (A6), D17.4 (A6), D18.4 (A6), D19.4 (A6)
/.16: D4.6 (Q3), D13.3 (C), D16.3 (A7), D17.3 (A7), D18.3 (A7), D19.3 (A7)
/.17: D5.12 (Q5), D12.9 (B3), D16.25 (A8), D17.25 (A8), D18.25 (A8), D19.25 (A8)
/.18: D5.15 (Q6), D11.11 (A4), D16.24 (A9), D17.24 (A9), D18.24 (A9), D19.24 (A9)
/.19: D5.16 (Q7), D16.21 (A10), D17.21 (A10), D18.21 (A10), D19.21 (A10)
/.20: D5.19 (Q8), D16.23 (A11), D17.23 (A11), D18.23 (A11), D19.23 (A11)
/.21: D5.6 (Q3), D16.2 (A12), D17.2 (A12), D18.2 (A12), D19.2 (A12)
/.23: D1.1 (A1), D1.2 (B1), D1.4 (C1), D1.5 (D1), D2.2 (Y1), D15.2 (B1)
/.24: D3.6 (Y2), D11.5 (A2), D11.9 (B3)
/.25: D2.4 (Y2), D7.10 (B3), D13.11 (G)
/.27: D14.3 (T1), D14.11 (T2), D15.11 (Y4)
/.28: D9.7 (1Y0), D16.20 (~CE)
/.29: D9.6 (1Y1), D17.20 (~CE)
/.30: D9.5 (1Y2), D18.20 (~CE)
/.31: D9.4 (1Y3), D19.20 (~CE)
/.32: D14.8 (/Q2), D16.22 (~OE), D17.22 (~OE), D18.22 (~OE), D19.22 (~OE)
/.33: D4.11 (C), D5.11 (C), D7.8 (Y3)
/.34: D16.26 (A13), D17.26 (A13), D18.26 (A13), D19.26 (A13), RB03.2, RB04.2
/.35: D16.27 (A14), D17.27 (A14), D18.27 (A14), D19.27 (A14), RB02.2, RB05.2
/.36: D6.19 (Q8), D9.13 (S0)
/.37: D6.6 (Q3), D9.3 (S1)
/~write: D1.6 (Y1)
AB0: D4.14 (D6), XM.19A (AB0); also elsewhere on the board
AB1: D4.13 (D5), XM.19B (AB1); also elsewhere on the board
AB2: D4.18 (D8), XM.18A (AB2); also elsewhere on the board
AB3: D4.17 (D7), XM.18B (AB3); also elsewhere on the board
AB4: D4.4 (D2), XM.17A (AB4); also elsewhere on the board
AB5: D4.3 (D1), XM.17B (AB5); also elsewhere on the board
AB6: D4.8 (D4), XM.16A (AB6); also elsewhere on the board
AB7: D4.7 (D3), XM.16B (AB7); also elsewhere on the board
AB8: D5.13 (D5), XM.14A (AB8); also elsewhere on the board
AB9: D5.14 (D6), XM.14B (AB9); also elsewhere on the board
AB10: D5.17 (D7), XM.13A (AB10); also elsewhere on the board
AB11: D5.18 (D8), XM.13B (AB11); also elsewhere on the board
AB12: D5.7 (D3), XM.12A (AB12); also elsewhere on the board
AB13: D11.6 (B2), XM.12B (AB13); also elsewhere on the board
AB14: D7.2 (B1), XM.11A (AB14); also elsewhere on the board
AB15: D7.5 (B2), XM.11B (AB15); also elsewhere on the board
DB0: R1.2, XM.7B (DB0); also elsewhere on the board
DB1: R2.2, XM.7A (DB1); also elsewhere on the board
DB2: R3.2, XM.6B (DB2); also elsewhere on the board
DB3: R4.2, XM.6A (DB3); also elsewhere on the board
DB4: R5.2, XM.5B (DB4); also elsewhere on the board
DB5: R6.2, XM.5A (DB5); also elsewhere on the board
DB6: R7.2, XM.4B (DB6); also elsewhere on the board
DB7: R8.2, XM.4A (DB7); also elsewhere on the board
GND: C1.2, C2.2, C3.2, C4.2, C5.2, C6.2, C7.2, C8.2, C9.2, C10.2, C11.2, C12.2, C13.2, D1.7 (GND), D2.7 (GND), D3.7 (GND), D4.1 (EN), D4.10 (GND), D5.1 (EN), D5.10 (GND), D6.1 (EN), D6.10 (GND), D7.7 (GND), D8.7 (GND), D9.2 (1STB), D9.8 (GND), D10.7 (GND), D11.7 (GND), D12.7 (GND), D13.7 (GND), D14.7 (GND), D15.7 (GND), D16.14 (Uss), D17.14 (Uss), D18.14 (Uss), D19.14 (Uss), RB01.1, XM.1A (GND), XM.1B (GND), XM.2A (GND), XM.2B (GND), XM.21B (GND); also elsewhere on the board
MEI: D3.2 (B1), D3.13 (B4), XM.24B (MEI); also elsewhere on the board
MEO: D3.11 (Y4), XM.24A (MEO); also elsewhere on the board
unnamed: B01.1 (K), D7.11 (Y4)
unnamed: B01.2 (A), R9.1
unnamed: D1.8 (Y2), D2.13 (A6), D3.12 (A4), D15.4 (A2)
unnamed: D1.9 (A2), D2.6 (Y3)
unnamed: D1.10 (B2), D11.4 (Y2)
unnamed: D1.12 (C2), D6.15 (Q6), D7.12 (A4)
unnamed: D1.13 (D2), D11.1 (Y1)
unnamed: D2.12 (Y6), D3.1 (A1)
unnamed: D6.2 (Q1), RB05.1
unnamed: D6.5 (Q2), D7.1 (A1)
unnamed: D6.9 (Q4), RB04.1
unnamed: D6.16 (Q7), D7.4 (A2)
unnamed: D8.11 (Y4), RB06.1
unnamed: D8.1 (A1), D8.2 (B1), D8.4 (A2), D8.5 (B2), D8.9 (A3), D8.10 (B3), D8.12 (A4), D8.13 (B4), D10.1 (A1), D10.2 (B1), D11.10 (Y3), RB08.2
unnamed: D10.3 (Y1), RB07.1
unnamed: D10.4 (A2), D10.5 (B2), D10.9 (A3), D10.10 (B3), D10.12 (A4), D10.13 (B4), RB01.2, RB08.1
unnamed: D7.3 (Y1), D11.2 (A1)
unnamed: D7.6 (Y2), D11.3 (B1)
unnamed: D2.9 (A4), D11.8 (A3), D13.8 (Y)
unnamed: D11.13 (Y4), D13.12 (H)
unnamed: D12.1 (Y1), D13.1 (A)
unnamed: D12.4 (Y2), D13.4 (D)
unnamed: D12.10 (Y3), D13.5 (E), D13.6 (F)
unnamed: D12.13 (Y4), D13.2 (B)
unnamed: D14.2 (D1), D14.9 (Q2), D15.10 (B3)
unnamed: D14.6 (/Q1), D15.9 (A3)
unnamed: D3.3 (Y1), D14.12 (D2)
unnamed: D2.8 (Y4), D15.1 (A1)
unnamed: D6.11 (C), D15.3 (Y1)
unnamed: D15.5 (B2), D15.8 (Y3)
unnamed: D7.9 (A3), D9.1 (1A), D15.6 (Y2)
unnamed: D2.10 (Y5), D15.12 (A4), D15.13 (B4)
unnamed: XM.10A (IEO), XM.10B (IEI)
TAKT: D2.11 (A5), XM.21A (TAKT); also elsewhere on the board
~IORQ: D2.3 (A2), XM.9B (/IORQ); also elsewhere on the board
~MAD: D11.12 (B4), XM.26A (/MAD); also elsewhere on the board
~MREQ: D2.5 (A3), XM.9A (/MREQ); also elsewhere on the board
~RD: D3.4 (A2), D3.5 (B2), XM.8B (/RD); also elsewhere on the board
~WR: D2.1 (A1), XM.8A (/WR); also elsewhere on the board

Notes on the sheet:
read 80h
write 80h
Dieses Signal wird auf der Platine bis dicht an Pin 27 von D16-D19 herangeführt.
chip enable
address enable
SEGMENTED ROM
Stromlaufplan
4484.897-00037
Strukturbyte
Steuerwort: M045 AASSxxxM M046 AASSxSxM M047 AASSSSxM
01h
02h
04h
08h
10h
20h
40h
80h
AA Adressbereich 00 0000h - 1FFFh 01 4000h - 5FFFh 10 8000h - 9FFFh 11 C000h - DFFFh
1988, © MPM 2017, Thomas Schramm 2020, Bert Lange
M037
6.10.2020
4x8k
8x8k
16x8k
70h
71h
72h
Brückenplan
Modul
M045
M046
M047
EPROM-Typ
2764
27128
27256
2x8k
M033

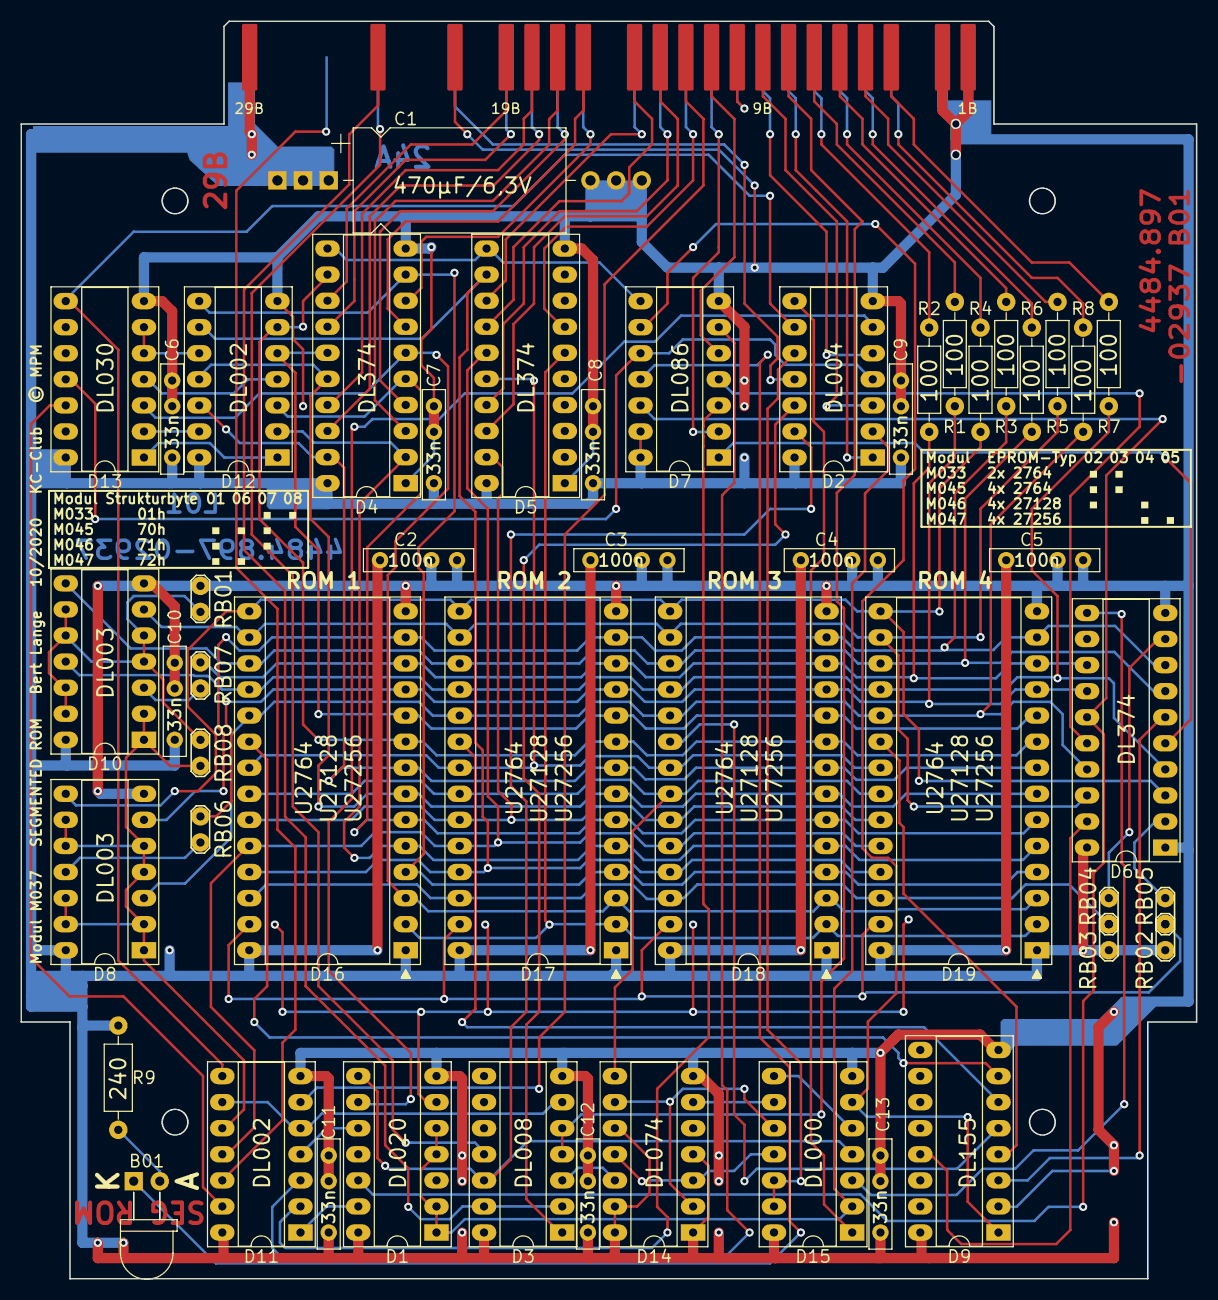
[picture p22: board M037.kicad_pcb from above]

Board: 2 copper layers, 114.5 x 122.5 mm, 51 parts (0 on the bottom side), 102 nets.

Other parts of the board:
X1: KC85_MODULSTECKVERBINDER; KC85_Modul_M037

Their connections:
+5V: X1.29A, X1.29B; also elsewhere on the board
AB0: X1.19A; also elsewhere on the board
AB1: X1.19B; also elsewhere on the board
AB2: X1.18A; also elsewhere on the board
AB3: X1.18B; also elsewhere on the board
AB4: X1.17A; also elsewhere on the board
AB5: X1.17B; also elsewhere on the board
AB6: X1.16A; also elsewhere on the board
AB7: X1.16B; also elsewhere on the board
AB8: X1.14A; also elsewhere on the board
AB9: X1.14B; also elsewhere on the board
AB10: X1.13A; also elsewhere on the board
AB11: X1.13B; also elsewhere on the board
AB12: X1.12A; also elsewhere on the board
AB13: X1.12B; also elsewhere on the board
AB14: X1.11A; also elsewhere on the board
AB15: X1.11B; also elsewhere on the board
DB0: X1.7B; also elsewhere on the board
DB1: X1.7A; also elsewhere on the board
DB2: X1.6B; also elsewhere on the board
DB3: X1.6A; also elsewhere on the board
DB4: X1.5B; also elsewhere on the board
DB5: X1.5A; also elsewhere on the board
DB6: X1.4B; also elsewhere on the board
DB7: X1.4A; also elsewhere on the board
GND: X1.1A, X1.1B, X1.2A, X1.2B, X1.21B; also elsewhere on the board
IE-Kette: X1.10A, X1.10B
MEI: X1.24B; also elsewhere on the board
MEO: X1.24A; also elsewhere on the board
TAKT: X1.21A; also elsewhere on the board
~IORQ: X1.9B; also elsewhere on the board
~MAD: X1.26A; also elsewhere on the board
~MREQ: X1.9A; also elsewhere on the board
~RD: X1.8B; also elsewhere on the board
~WR: X1.8A; also elsewhere on the board

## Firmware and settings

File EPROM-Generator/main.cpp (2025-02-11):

/*
 * (c) 2020 Bert Lange
 *
 * EPROM-Generator für M037-Module (M045/M046/M047)
 *
 * Applikation
 */
#include "romstart.h"
#include <QApplication>
#include <QStyleFactory>

int main( int argc, char* argv[])
{
    QApplication::setStyle(QStyleFactory::create( "Fusion"));

    QApplication app( argc, argv);
    Romstart window;
    window.show();
    return app.exec();
}

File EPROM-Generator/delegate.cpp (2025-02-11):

/*
 * (c) 2020 Bert Lange
 *
 * EPROM-Generator für M037-Module (M045/M046/M047)
 *
 * Spezielle Interaktionen die große Tabelle
 */
#include "delegate.h"

//#include <iostream>
#include <QtGui>
#include <QApplication>
#include <QSpinBox>
#include <QDebug>


Delegate::Delegate( QObject *parent) : QItemDelegate( parent)
{    
}


QSize Delegate::sizeHint( const QStyleOptionViewItem &option, const QModelIndex &index) const
{
    QSize sz = QItemDelegate::sizeHint(option, index);
    int w = sz.width();
    if( index.column() == 0)    // Frage: wie Zugriff auf enum von datamodel
    {
        //cout << "width: " << w << endl;
        if( w > 20)
        {
            w -= 20;
        }
        else
        {
            w = 1;
        }
    }
    if( index.column() == 11)
    {
        w = 65;
    }
    sz.setWidth( w);
    return sz;
}


void Delegate::paint(QPainter *painter, const QStyleOptionViewItem &option, const QModelIndex &index) const
{
    QStyleOptionSpinBox spin;
    QStyleOptionButton remove_button;
    QRect r = option.rect;
    int x, y, w, h;

    // erstmal normal malen
    QItemDelegate::paint( painter, option, index);

    switch( index.column())
    {
        case 0:
            // dann die Buttons
            w = 30;
            h = 30;
            x = r.left() + r.width() - w;
            y = r.top();
            spin.rect = QRect( x, y, w, h);

            if( index.row() > 0)
            {
                spin.stepEnabled |= QAbstractSpinBox::StepUpEnabled;
            }
            if( index.row() < ( index.model()->rowCount() - 1))
            {
                spin.stepEnabled |= QAbstractSpinBox::StepDownEnabled;
            }
            QApplication::style()->drawComplexControl( QStyle::CC_SpinBox, &spin, painter, NULL);
            break;

        case 11:
            w = 65;
            h = 30;
            x = r.left();// + r.width() - w;
            y = r.top() - 1;
            remove_button.rect = QRect( x, y, w, h);
            remove_button.text = "Entfernen";
            remove_button.state = QStyle::State_Enabled;
            QApplication::style()->drawControl( QStyle::CE_PushButton, &remove_button, painter);
            break;
    }
}


bool Delegate::editorEvent(QEvent *event, QAbstractItemModel *model, const QStyleOptionViewItem &option, const QModelIndex &index)
{
    if( event->type() == QEvent::MouseButtonRelease)
    {
        // for preview
        //emit activated(( unsigned int) index.row());

        // check column
        switch( index.column())
        {
            case 0:
            {
                 QMouseEvent * e = (QMouseEvent *)event;
                 QRect r_up = option.rect;

                 int ypos_in_field = e->position().y() - r_up.y();
                 //cout << "Clicked! (" << e->position().y() << ")" << endl;
                 if( r_up.contains( e->pos()))
                 {
                     if( ypos_in_field < 15)
                     {
                        emit moveButtonUpPressed(( unsigned int) index.row());
                     }
                     else
                     {
                        emit moveButtonDownPressed(( unsigned int) index.row());
                     }
                     return true;
                 }
                 break;
            }

            case 11:
            {
                 QMouseEvent * e = (QMouseEvent *)event;
                 int clickX = e->position().x();
                 int clickY = e->position().y();

                 QRect r = option.rect;
                 int x, y, w, h;
                 x = r.left() + r.width() - 65;
                 y = r.top();
                 w = 65;
                 h = 30;

                 if( clickX > x && clickX < x + w )
                 if( clickY > y && clickY < y + h )
                 {
                     emit removeButtonPressed( index.row());
                     return true;
                 }
            break;
            }
        }
    }
    else if( event->type() == QEvent::KeyPress)
    {
        //cout << "KeyPress on row: " << index.row() << endl;
        //emit activated(( unsigned int) index.row());
    }
    else
    {
        //cout << "Event: " << event->type() << endl;
        // 2 = MouseButtonPress
        // 6 = KeyPress
    }
    return QItemDelegate::editorEvent( event, model, option, index);
}

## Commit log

2021-09-20 erste Unterlagen
    [M037_Stueckliste.xls]
2021-09-20 KiCad-Projekt ergänzt
    [M037-B_Cu.gbr, M037-B_Mask.gbr, M037-Edge_Cuts.gbr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]
2021-09-29 Modulblende hinzugefügt
    [Blende-B_Cu.gbr, Blende-B_Mask.gbr, Blende-B_Paste.gbr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]

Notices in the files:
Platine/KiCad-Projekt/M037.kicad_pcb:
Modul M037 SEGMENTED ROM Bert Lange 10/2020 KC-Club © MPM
